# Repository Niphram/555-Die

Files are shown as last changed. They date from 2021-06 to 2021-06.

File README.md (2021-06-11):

# 555 Die

Small kit I designed for my brother, may be interesting to some.
Designed using KiCAD 5.

## Parts

| Designator | Value | Package |
| --- | ---: | :---: |
| R13 - R16 | 1kΩ | Axial DIN0207 |
| R2, R3, R5 - R12 | 10kΩ | Axial DIN0207 |
| R1, R4 | 4.7MΩ | Axial DIN0207 |
| D1 - D7 | LED | 5mm |
| Q1, Q3 | BC557 | TO-92 |
| Q2, Q4, Q5 | BC647 | TO-92 |
| C1 | 0.1μF | Disc D5.0mm W2.5mm P2.50mm |
| C2 | 1μF | Radial D5.0mm P2.5mm |
| SW1 | Tact Switch | 6mm |
| U1 | NE555 |  DIP-8 (Optional Socket) |
| U2 | CD4017 |  DIP-16 (Optional Socket)  |
| BT1 | Powersource (3V-9V) |

> R4 and R1 can be changed to alter timings.

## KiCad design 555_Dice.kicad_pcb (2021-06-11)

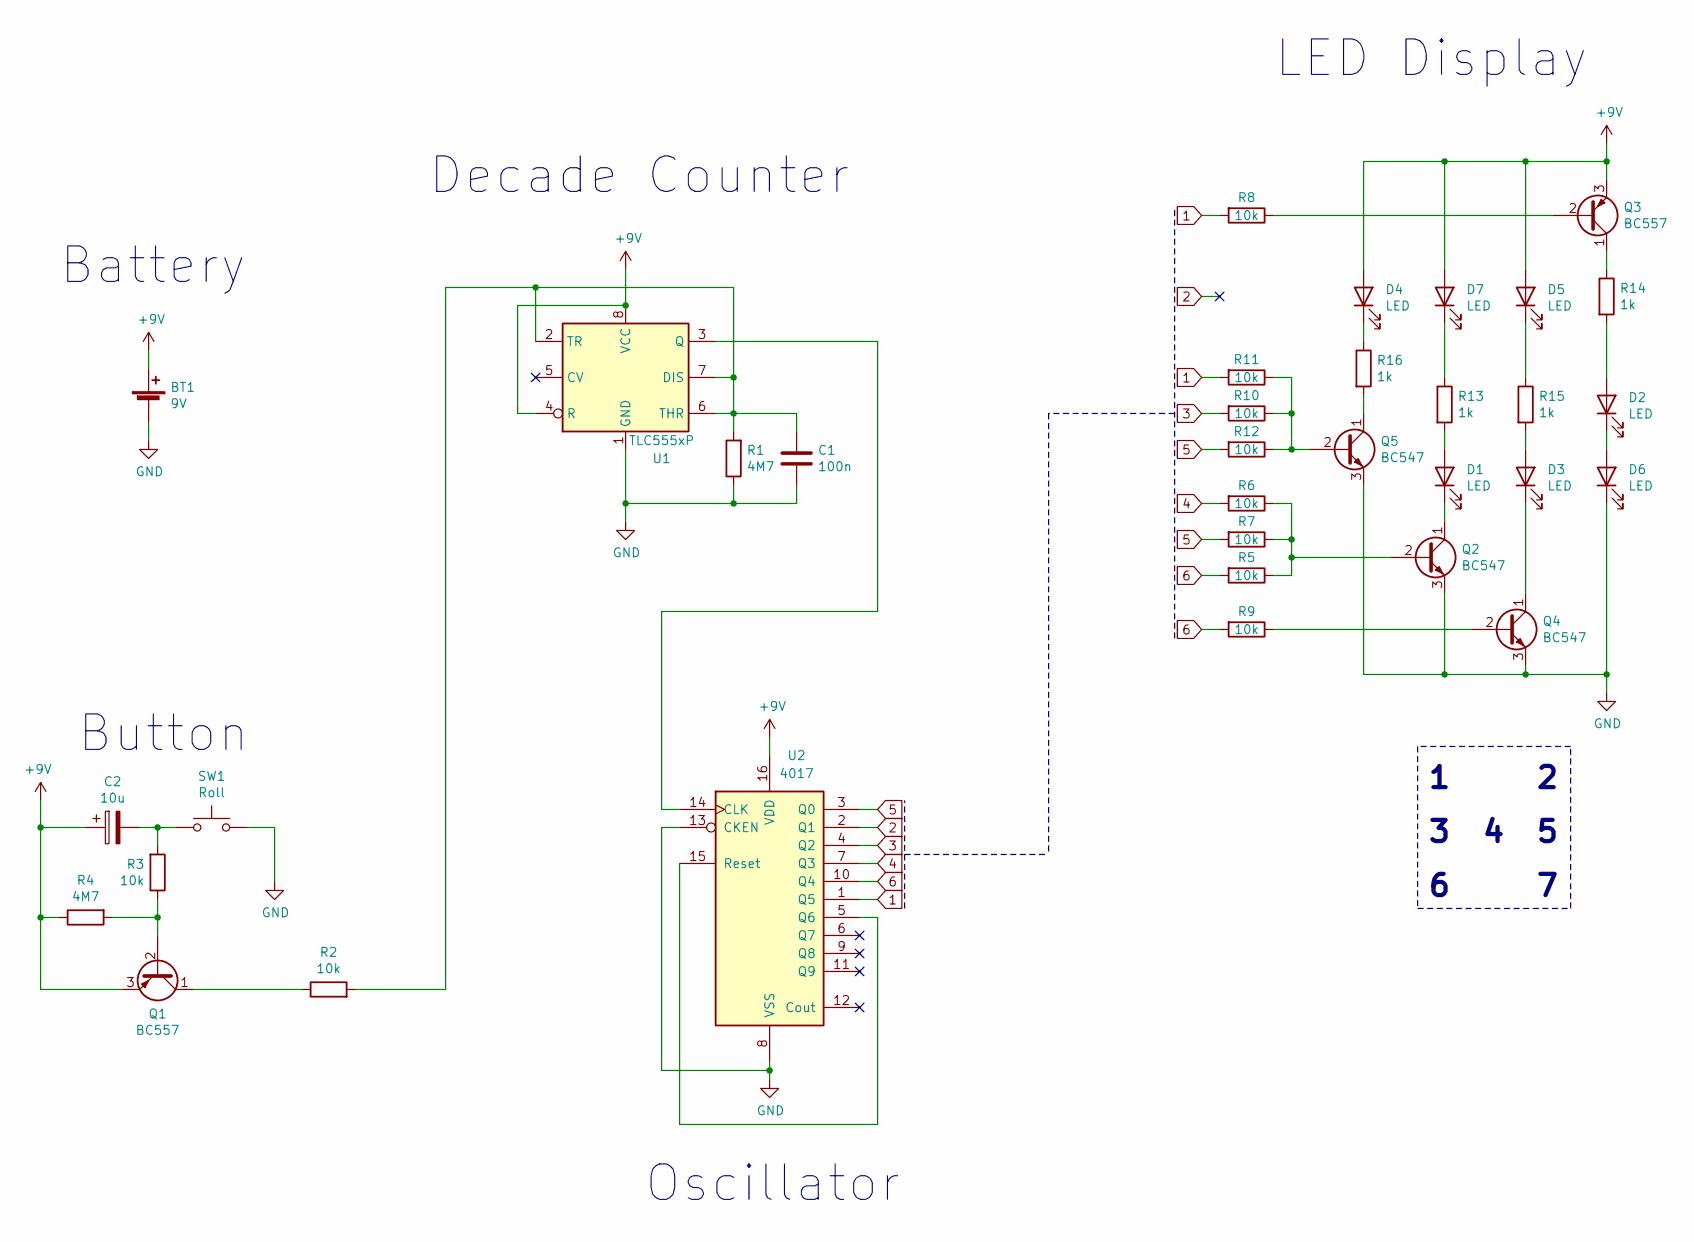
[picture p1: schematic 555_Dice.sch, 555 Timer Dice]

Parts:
BT1: 9V; TerminalBlock_bornier-2_P5.08mm
C1: 100n; C_Disc_D5.0mm_W2.5mm_P2.50mm
C2: 10u; CP_Radial_D5.0mm_P2.50mm
D1, D2, D3, D4, D5, D6, D7: LED; LED_D5.0mm
Q1, Q3: BC557; TO-92_HandSolder
Q2, Q4, Q5: BC547; TO-92_HandSolder
R1, R4: 4M7; R_Axial_DIN0207_L6.3mm_D2.5mm_P10.16mm_Horizontal
R2, R3, R5, R6, R7, R8, R9, R10, R11, R12: 10k; R_Axial_DIN0207_L6.3mm_D2.5mm_P10.16mm_Horizontal
R13, R14, R15, R16: 1k; R_Axial_DIN0207_L6.3mm_D2.5mm_P10.16mm_Horizontal
SW1: Roll; SW_PUSH_6mm_H4.3mm
U1: TLC555xP; DIP-8_W7.62mm_Socket_LongPads
U2: 4017; DIP-16_W7.62mm_Socket_LongPads

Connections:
1: R8.2, R11.2, U2.1 (Q5)
2: U2.2 (Q1)
3: R10.2, U2.4 (Q2)
4: R6.2, U2.7 (Q3)
5: R7.2, R12.2, U2.3 (Q0)
6: R5.2, R9.2, U2.10 (Q4)
+9V: BT1.1 (+), C2.1, D4.2 (A), D5.2 (A), D7.2 (A), Q1.3 (E), Q3.3 (E), R4.1, U1.4 (R), U1.8 (VCC), U2.16 (VDD)
GND: BT1.2 (-), C1.2, D6.1 (K), Q2.3 (E), Q4.3 (E), Q5.3 (E), R1.1, SW1.1, U1.1 (GND), U2.8 (VSS), U2.13 (CKEN)
unnamed: C1.1, R1.2, R2.2, U1.2 (TR), U1.6 (THR), U1.7 (DIS)
unnamed: C2.2, R3.2, SW1.2
unnamed: D1.1 (K), Q2.1 (C)
unnamed: D1.2 (A), R13.2
unnamed: D2.1 (K), D6.2 (A)
unnamed: D2.2 (A), R14.2
unnamed: D3.1 (K), Q4.1 (C)
unnamed: D3.2 (A), R15.2
unnamed: D4.1 (K), R16.1
unnamed: D5.1 (K), R15.1
unnamed: D7.1 (K), R13.1
unnamed: Q1.1 (C), R2.1
unnamed: Q1.2 (B), R3.1, R4.2
unnamed: Q2.2 (B), R5.1, R6.1, R7.1
unnamed: Q3.1 (C), R14.1
unnamed: Q3.2 (B), R8.1
unnamed: Q4.2 (B), R9.1
unnamed: Q5.1 (C), R16.2
unnamed: Q5.2 (B), R10.1, R11.1, R12.1
unnamed: U1.3 (Q), U2.14 (CLK)
unnamed: U2.5 (Q6), U2.15 (Reset)

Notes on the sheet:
Battery
Button
Oscillator
Decade Counter
LED Display

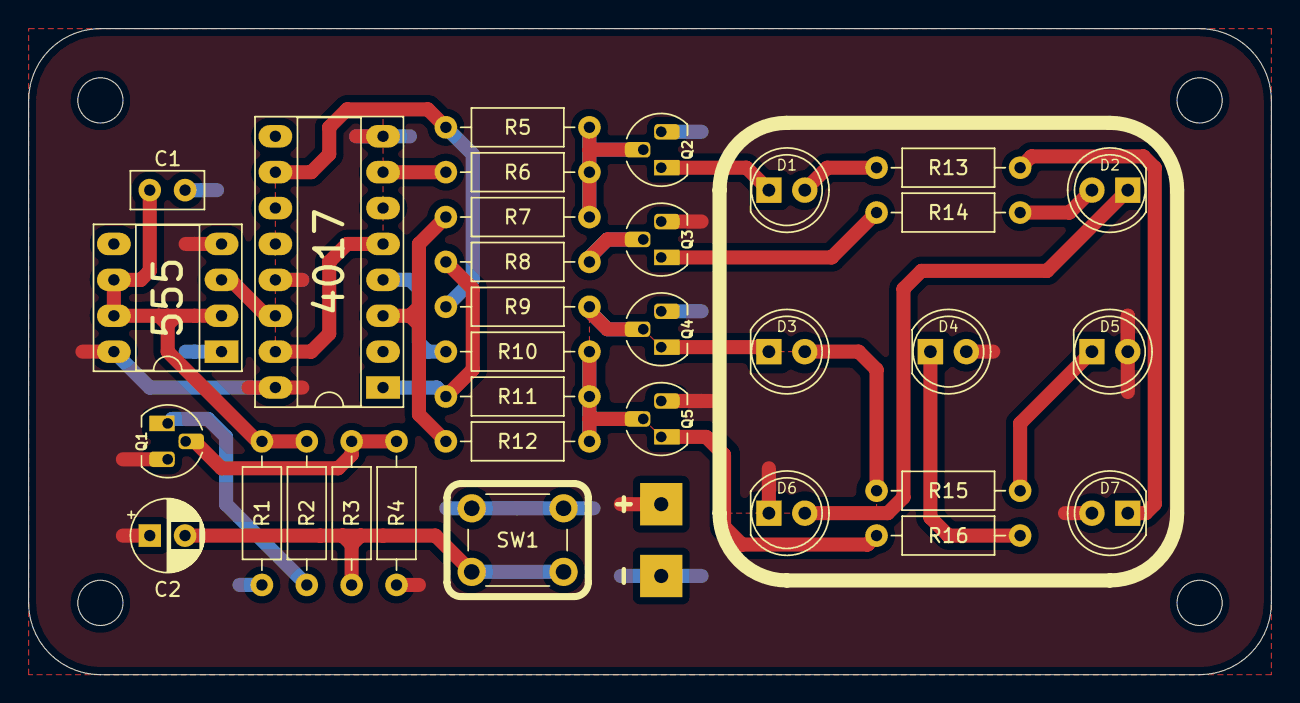
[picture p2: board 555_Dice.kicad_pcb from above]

Board: 2 copper layers, 87.9 x 45.7 mm, 34 parts (0 on the bottom side), 28 nets.
